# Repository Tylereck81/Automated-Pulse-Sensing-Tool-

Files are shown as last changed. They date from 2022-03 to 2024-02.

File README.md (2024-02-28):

# Automated Pulse Sensing Tool
APST_mainpic 

2021-2022 NDHU Undergraduate Project  
Group Members: Tyler Edwardo Eck  
Advisor: 顏士淨 (Shi-Jim Yen)  

## Introduction 
Automated Pulse Sensing Tool is a tool that allows users to measure their pulse with ease. With the simple push of a button, this tool will detect the pulse location on a person's wrist, move the sensor to that location, and record the TCM (Tradional Chinese Medicine) pulse readings. Finally, the results will be automatically uploaded to the cloud for remote doctors to observe.    

This project, including both the hardware and software, was exclusively developed and submitted as my final entry for the 2021 NDHU Undergraduate Project.      

Within the repository, you will find both the documentations for the project, including the presentations, poster, and research report, and the two main programs used together to control the tool. 

## Hardware 
The Automated Pulse Sensing Tool incorporates multiple hardware components that work together to give the tool its utility. The following is what was used:     
     
### Creality CR10s 3D printer   
The recycled 3D printer was used as the main base for my project. It provides a main hand-rest area for patients with all the necessary motors and stop switches connected in an X,Y, and Z plane.     
    

### HK-2019 Cylindrical Pusle Sensor 
This 200Hz pulse sensor measures both pulse and pressure for TCM pulse points.    
 

### StereoLabs ZED dual camera 
The camera was specifically chosen for its high frame rate and long-range 3D sensing.    
 

### 3D-printed Component 
This 3D printed component was designed to mount the camera and sensors together for the motors to move.    
 

### Final Tool 
The completed hardware with all the subcomponents mentioned above is shown below.  
 
    
## Software 
The Automated Pulse Sensing Tool needs software to move step motors through Arduino and a Python program to communicate with Arduino and process motor movement. The Python program also acts as the main GUI that patients and doctors will interact with. Therefore, in the Hardware/Arduino folder, the "Motor_Movement.ino" is used to move the motors and in the Software GUI folder, "APST_GUI.py" is the main python program.     
     
The APST_GUI.py was designed and implemented using Tkinter, a package in the standard Python interface GUI toolkit. As shown in diagram below, the GUI consists of 4 main parts: 

label

1. Camera - shows users a live feed of the camera and its detection of the pulse point.   
     
2. Options - controls motors manually with arrows and step selection, controls initiation of scan, and displays connection information regarding the pulse sensors, motors, and camera.  
   
3. Graph - displays the graph of the pulse that was taken.    
   
4. Information - allows users to enter additional information about the graph including name, date, and description (optional). This section also includes the Upload button that is necessary to send data via Firebase to the cloud.    

## Setup
The Automated Pulse Sensing Tool requires both the necessary software configurations and the physical tool available in order to sucessfully record and upload data. However, because the physical tool is property of the NDHU AI Lab, I can only include the software configurations to run the main python GUI program.    

In order to run the programs locally, follow the necessary steps below:    

1.  Download and install [Anaconda](https://docs.anaconda.com/anaconda/install/index.html) - Python 3.5 or 3.6
     
2.   Create an environment and download the necessary packages below using "conda install".   
     * Numpy 
     * Matplotlib
     * Tk - Tkinter 
     * Pillow - Image, ImageTk
     * OpenCv
     * Serial 
     * Mediapipe 
     * Pyrebase
   
3. Download and install [Arduino IDE](https://www.arduino.cc/en/software)
4. Download USB Driver for the HK2019 Pulse and Pressure Sensor - instructions and website found in "USB-- READ ME--" file in project. 
5. Upload "Motor_Movement" file to the Arduino Board using Arduino IDE. 
6. Run the main "APST_GUI" python file.

If all steps were properly executed, the main GUI screen will appear as shown below.

<p align="center">
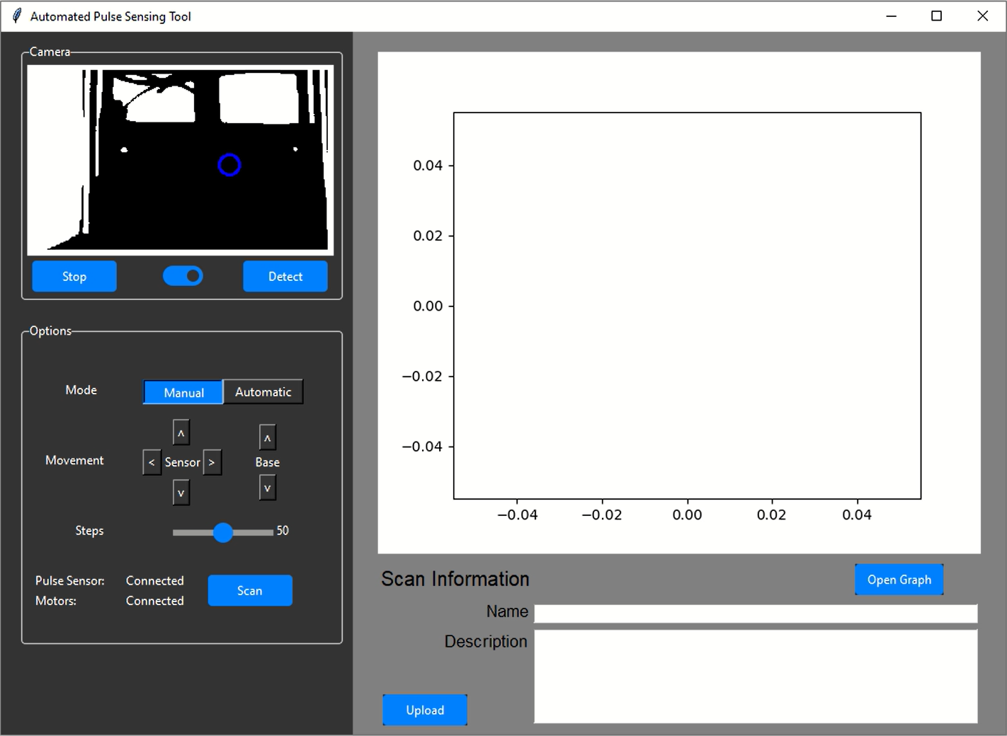
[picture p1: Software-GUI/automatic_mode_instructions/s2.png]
  
</p>

## Instructions
In order to run the program successfully, ensure the pulse sensor, arduino, and camera are all connected via USB and the computer recongizes them.
 
The two modes that are available are Manual and Automatic. Manual is selected by default.    

 * ### Manual 
Manual mode is intended for doctors to use as they are given the choice to manually move the motors and start scan when desired. The following steps are the sequence that doctors can follow:
     
1. The motor movement is initiated through the Options menu shown below. The sensor can be moved on the X and Z axis by through the Sensor movement arrows. The base, where the patients hand would lay, can also be moved on the Y axis through the Base movement arrows. Lastly, the doctors can manually control the steps that the motors can take for a given click of the arrow. By adjusting the Steps slider, each movement can be shortened or lengthened.      
          
op      
     
2. After a desired location is reached, the doctor can activate the detection algorithm, through the "Detect" button in the Camera section, to determine if the location of the pulse point is in the blue circle; this blue circle displays the exact point where the sensor will read. The "Stop" button is used to freeze the frame so that the doctor may have a chance to click on the point that the sensor should move to. Clicking the point activates the motor movement to have the sensor move directly beneath the selected pulse point.       
     
        

3. When ready to scan, the "Scan" button in the Options menu should be pressed. A seperate screen will pop up to indicate the scan is taking place. When finished, the "Stop" button should then be pressed to stop the scan. To see a more detailed version of the recorded graph, the "Open Graph" button in the graph section can be pressed. To "cut" or record a subsection of the graph, the mouse's left click is used to select start point and right click to select end point.
      
g5
       
g2
     
5.  Lastly, information about the patient can be entered in text area and uploaded by pressing the Upload button.    
     
u5

* ### Automatic
Automatic mode is intended for patients to use and includes user-friendly instructions that patients should read carefully. 

1. When the Automatic button is pressed in the Options section, a seperate instruction screen will appear for users to read. These instructions include different warnings and proper hand form for an accurate scan.    

     
         
      

2. After the instructions have been read, the "Finish" button will be enabled to press which starts the automation process. The tool will automatically detect the pulse point, select the pulse point, move motors to that point, and scan for 30 seconds. When finished, the patient will be prompted to enter information and then press the "Upload" button as shown in the Manual section.

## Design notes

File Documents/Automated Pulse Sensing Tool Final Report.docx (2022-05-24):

國立東華大學資訊工程系

Automated Pulse Sensing Tool

National Dong Hwa University

110學年度大學部畢業專題研究報告

110 CSIE Undergraduate Project Report

指導教授Advisor: 顏士淨 (Shi-Jim Yen)

專題參與人員Team Member: Tyler Edwardo Eck

中 華 民 國　　111 　年　　05　　月 　20 　 日

國立東華大學資訊工程學系

專題報告原創性聲明

National Dong Hwa University

Department of Computer Science and Information Engineering

Statement of Originality

本人鄭重聲明：

所呈交的專題報告是在指導老師指導下進行的研究工作及取得的研究成果。除文中已經註明引用的內容外，本報告不包含任何其他個人或集體已經發表或撰寫過的研究成果。對本文的研究做出重要貢獻的個人與集體，均已在文中以明確方式標明。若有違上述聲明，願依校規處分及承擔法律責任。

I hereby affirm that the submitted project report is the result of research under the supervision of my advisor. Except where due references are made, the report contains no material previously published or written by another person or group. All significant facilitators to the project have been mentioned explicitly. Should any part of the statement be breached, I am subject to the punishment enforced by the University and any legal responsibility incurred.

學號Student No. | 學生姓名Name | 親筆簽名Signature

. 410821337 Tyler Edwardo Eck .

日 期 Date: 5/20/2022

ACKNOWLEDGEMENTS

In the process of conducting this project, I have received an abundance of support.

Firstly, I would like to thank my Advisor, Professor 顏士淨 (Shi-Jim Yen), for the assistance and resources needed to conduct such a complex project. The guidance that he gave me helped to overcome many problems that I found myself stuck with. Moreover, his expertise and knowledge in this field gave me insight into the paths that I had taken to complete this project.

I would also like to thank邱顯棟 (Jelly) and Serkan Kavak, two employees of the AI Lab, whose advice and one-on-one help pushed me to overcome the many programming obstacles that stood in my way.

With the help of the ⼨關尺辨 識 team and permission from my advisor, I was able to implement their pulse point detection algorithm into my tool. Without this, my project would not have been as engaging and practical.

Lastly, I would like to thank my parents, family, and friends whose value of support was immeasurable. Without this, I wouldn’t have pushed myself hard enough to make this project the best that it could be. They helped keep me grounded and were there to lend a helping hand if needed.

ABSTRACT

Due to the rise in popularity of technology, especially of the internet, people have sought to use creative and functional methods of implementing it in their daily life. Automation, for instance, can have a huge impact in the amount of time saved doing remedial tasks. As seen in the manufacturing sector, both throughput and speed are pushed to the limit with industrial robots in the place of working human beings. This exponential improvement that automation brings should be applied to something more important such as the medical field.

Combining automation with medical tools creates a crossroad for the tool proposed in this project. With an automated pulse sensor that can remotely record a person’s pulse faster, medical checkups for the elderly living in remote areas becomes easier and more efficient. By using a cloud-based platform, this tool can also give doctors the ability to remotely observe multiple people’s pulse recordings at any given time. Limitations on location and time would be eradicated as a result of the implementation of this tool.

Keywords: automation, medical, pulse, cloud-based

CONTENTS

Statement of Originality …………………………………………………1

Acknowledgments ……………………………………………………….2

Abstract …………………………………………………………………...3

Introduction ……………………………………………………………….5

Motivation and Research Problem ……………………….…………....7

Research Method ………………………………………………………..8

Program Execution ……………………………………………………..15

Research Results (Discussion) ………………………………………..25

Conclusion ……………………………………………………………….28

References ……………………………………………………………....29

INTRODUCTION

In this evolving technological era, it is common to find ourselves dependent on automation technology whether it may be for a simple smart home device or something more complex such as a self-driving car (autonomous vehicle). Regardless, it is important to note that this fundamental use of automation can have a drastic impact on our seemingly difficult life. As popularity and demand grow, I believe that the next logical step is to implement automation in more important roles such as for medical purposes. By doing this, more time will be saved which may potentially save more lives.

Due to its popularity here in Eastern Taiwan, the specific medical procedure that I want to automate is pulse diagnosis in Traditional Chinese Medicine (TCM). As opposed to pulse diagnosis in western medicine that retrieves little information from a single point, TCM pulse diagnosis focuses on three locations, cun, guan and chi, on a person’s wrist to get the condition of the heart, liver, and kidney respectively. Although it is argued that TCM pulse diagnosis results are biased and only dependent on the practitioner’s experience and intuition, there have been many studies that aim to quantify the methods and assessments that can be drawn from the diagnosis. Moreover, most of the Taiwanese population, especially the elderly, rely on TCM assessments and consultations when they’re sick.

Therefore, with the advantages that automation brings and the popularity of Traditional Chinese Medicine in Taiwan, I propose a fully automated pulse sensing tool that will allow for users to measure their pulse with ease.

With the simple push of a button, this tool will detect the pulse location on a person’s wrist, move the pulse sensor to that location, and then finally make a digital recording of the pulse reading that will automatically be uploaded to the cloud.

As a result, the pulse reading can be analyzed by a doctor anywhere in the world making it more convenient for patients to see the doctors and for doctors to analyze and assess pulse diagnosis.

MOTIVATION AND RESARCH PROBLEM

Technology has solved many of our proximity problems whether it may be remote schooling due to COVID-19 or online conferences for company chains in different locations. The value of being able to connect with each other regardless of our location is quite essential in this modern age. Although we take it for granted, this idea of connection must be pushed to its limit. Therefore, the motivation of this project is to extend this connection to people who are physically unable to go for frequent doctor visits as a result of living in remote areas.

Small villages, especially in the east of Taiwan, lack the efficient number of doctors and special experts that are needed due to high numbers of elderly population living in those areas. Because of this, a lot of people need to travel far distances just to get a routine check-up. This poses a problem when they are physically unable to go due to health conditions, lack of transport, or the dynamic COVID-19 restrictions. The proposed tool allows for convenience as the goal is to make it accessible for people to send their information remotely to the doctor for examination.

RESEARCH METHOD

The project’s goal was to make an automated system that remotely transmits data. It needed both the necessary hardware to move motors and measure the pulse and the necessary software for detection of the wrist location, GUI for users, and the transmission of data. Therefore, I have split the project into two main parts as shown below: hardware and software

I. Hardware

The three main hardware components necessary to complete the project were the step motors to move the sensor, the camera as digital input for detection, and the pulse sensor to measure the pulse. Fortunately, I was provided with a Creality CR10s 3D printer that had all the necessary motors with its stop switches connected in an X,Y,Z plane shown below in Figure 1.

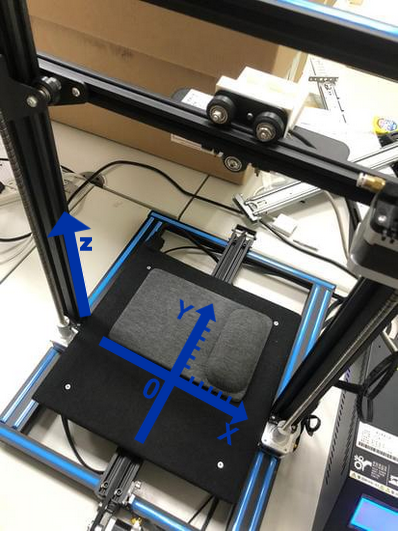
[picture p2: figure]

Figure 1: 3D printer with dimensions

The repurposing of this 3D printer required reprogramming the stepper motors that were connected to the motherboard. The motherboard, which is housed separately with the battery, is an Arduino2560 microcontroller and can therefore be controlled using the Arduino IDE. After the reprogramming was done, the motors could move in accordance with the X, Y, and Z Cartesian plane based on coordinates that was supplied to it through the serial.

The pulse sensor and camera were both provided by the lab as well. The pulse sensor is a HK-2019 Cylindrical Pulse Sensor. This 200Hz pulse sensor, as shown in Figure 2 (left), measures both pulse and pressure. The camera is a StereoLabs ZED dual camera as shown in Figure 2 (right). Because the website specifically advertises it for autonomous robotics due to its high frame rate and long-range 3D sensing, it was selected for the project.

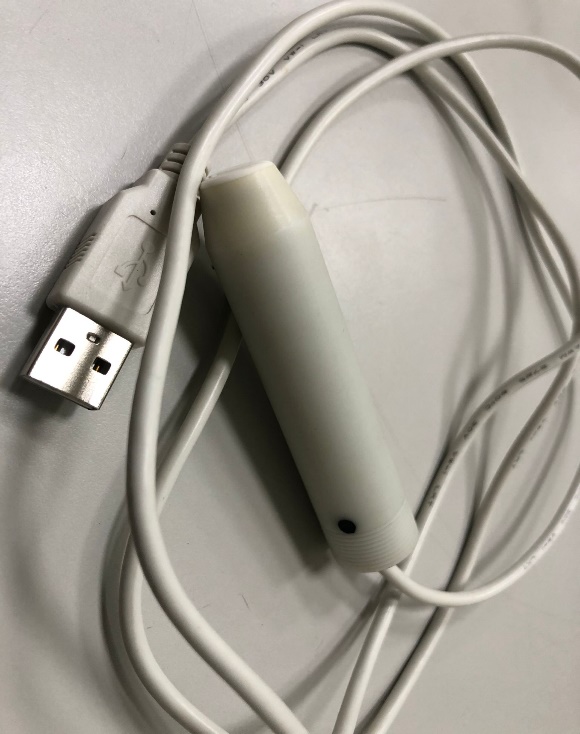
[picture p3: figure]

Figure 2: Pulse Sensor and ZED Dual Camera

Lastly, to mount both the camera and the sensor together for the motors to move, I had to learn how to design a 3D model and how to print using a 3D printer. Fortunately, the lab had a functioning 3D printer to my disposal, so I designed and printed a 3D-printed part shown below in Figure 3. (On the left shows the design of the part in the software and the right shows the printed piece).

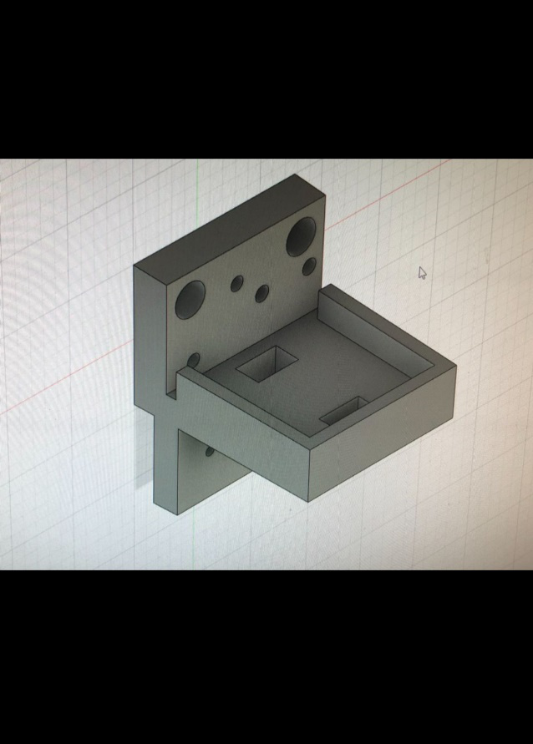
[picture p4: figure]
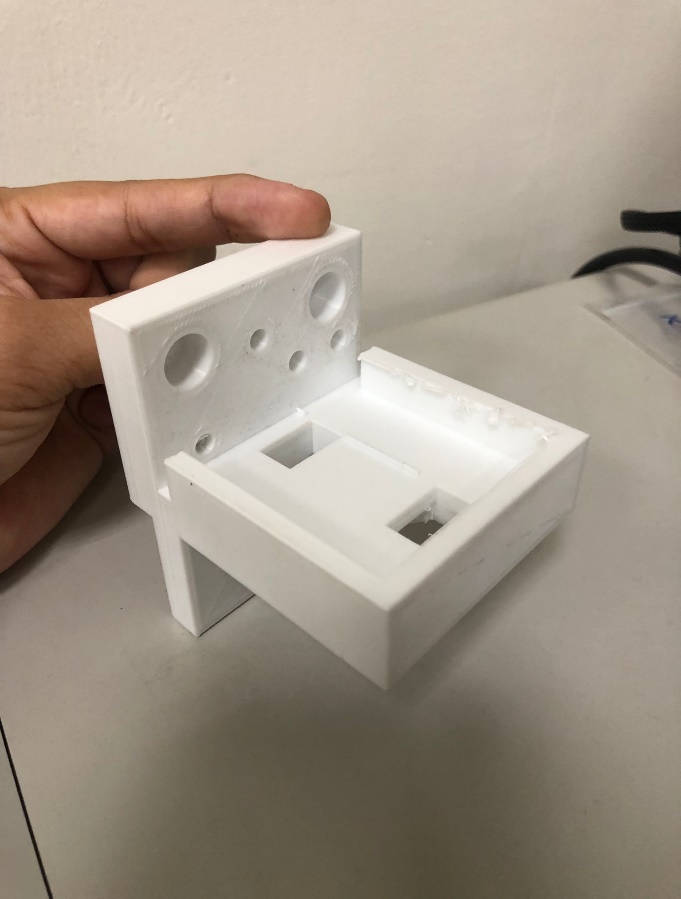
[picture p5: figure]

Figure 3: 3D-printed part

After all the necessary hardware configurations were done, the right USB drivers were installed, and USB extensions were added to each hardware component, the final hardware product was completed.

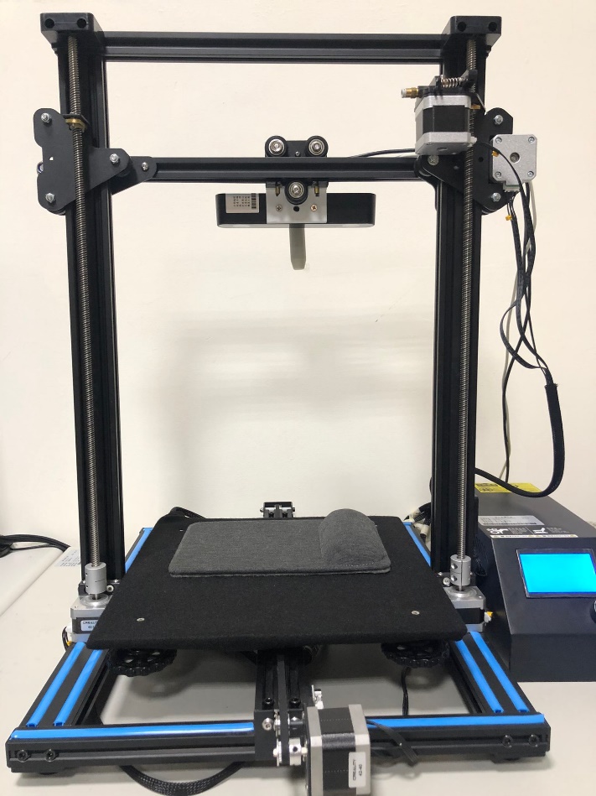
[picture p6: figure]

Figure 4: Completed Hardware

II. Software

There were two main portions of the project that consisted of software: The reprogramming of the Arduino and the GUI for the doctors/patients to use. These two programs will communicate with each other via the serial to have the motors move based on the specifications made in the GUI, thus successfully connecting the hardware and the software together.

The Arduino language, which is a language that uses C++, is a simple language used for the wiring and programming of Arduino microcontroller boards. As stated in the Hardware section, the motherboard used in the Creality 3D printer is an Arduino Mega 2560 running Marlin 2.0, the firmware used for all Creality printers. However, with simple programming done in the Arduino IDE, I successfully wrote a function that would constantly listen for coordinates through the serial. With these coordinates, I moved the X,Y, and Z coordinate motors with the help of an official Arduino library called SpeedyStepper. Shown below is a snippet of the Arduino code that constantly loops to listen for coordinates.

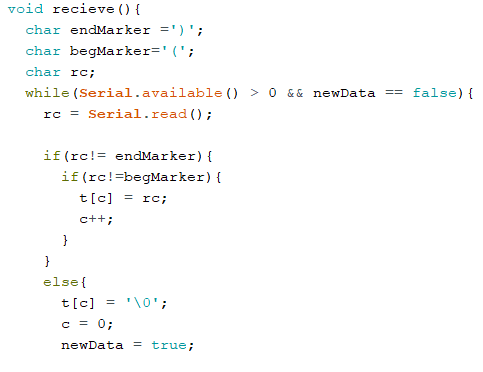
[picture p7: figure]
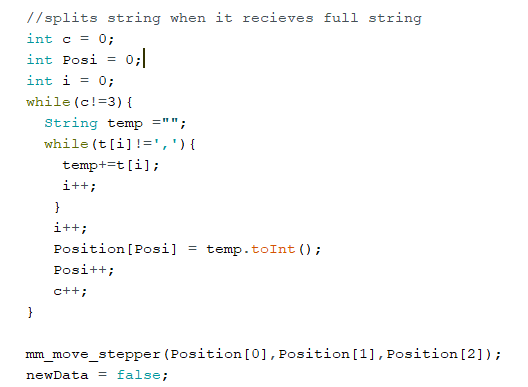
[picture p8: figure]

Figure 5: Arduino Code

Based on previous knowledge of GUI designing and implementation, I decided to use Tkinter, a package in the standard Python interface GUI toolkit, to construct a user-friendly interface for the doctors and patients to use. As shown below in Figure 6, the GUI consists of 4 parts:

1.) Camera – the section on the top left to show users a live feed of the camera and its detection of the pulse point
2.) Options – the section on the bottom left to switch between the two main modes: Manual and Automatic, control the motors manually with arrows and step selection, and start the scan when needed. The section also gives connection information regarding the pulse sensor, motors, and camera.
3.) Graph – the section to display, examine, and manipulate the graph taken.
4.) Information – the section on the bottom right to give additional information of the graph including the name, date, and a description (if needed). After all necessary information is inputted, an upload button allows for the user to send the data via Firebase to the cloud for evaluation.

Figure 6: Automated Pulse Sensing Tool GUI

Lastly, the detection algorithm used to detect the pulse point was developed by the ⼨關尺辨 識 group and was implemented into this project. The algorithm calculates the point by using a Python package called Mediapipe. As shown below, Mediapipe can detect a hand and identify 21 uniquely marked points on the hand known as landmarks. It is with 11 of these 21 landmarks that the algorithm calculates and marks the points in the Camera section.

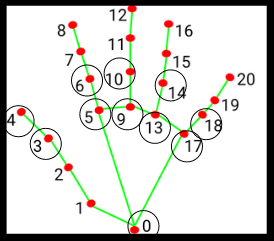
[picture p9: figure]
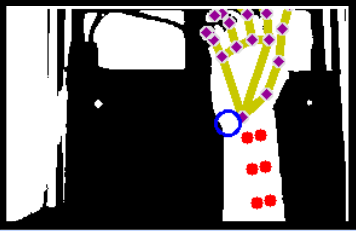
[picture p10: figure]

Figure 7: Automated Pulse Sensing Tool GUI

PROGRAM EXECUTION

The main flow of the program starts with the detection and recognition of all connected devices, including the motors from the Arduino, the pulse sensor, and the camera that are all connected via USB. After everything is confirmed to be connected, the user must select one of the two modes to run: Manual or Automatic

The default mode, manual mode, allows for a more interactive and hands-on experience which would most likely be done by a doctor. Movement of the motors can simply be done by selecting the number of millimeters each press should take and then pressing the Up, Down, Left, and Right buttons located in the Options section as shown in Figure 8.

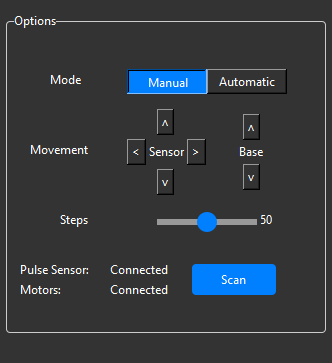
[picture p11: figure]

Figure 8: Manual Mode: Selection of Cm per Step

To aid the doctor in reaching the proper x and y coordinate of the pulse point, the detect button should be pressed to activate the detection algorithm. The live camera feed will display the calculated and marked pulse point on the screen. Due to its fast-dynamic calculations, the algorithm’s marking may change abruptly. To combat this, the Stop button should be pressed to stop the frame of the camera. From this point, the doctor can press where the pulse sensor, which is marked on the screen as a blue circle, should go and the motors will move to that location. Shown below in Figure 9 is the flow of this operation.

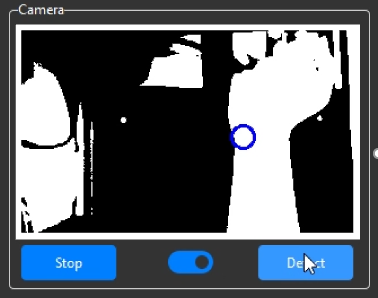
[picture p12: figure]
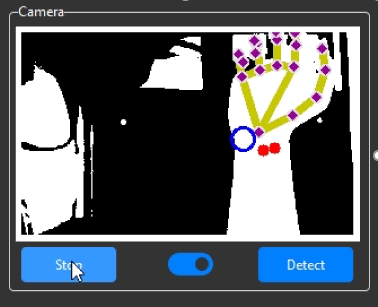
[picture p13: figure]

Figure 9: Manual Mode: Detection of Pulse Location

After the x and y coordinates have been reached, the doctor can then manually move the Z-axis sensor motor to the necessary height. When the desired location is reached, the scan button can then be pressed to graph the pulse and pressure taken from the pulse sensor and the stop button can be pressed to finish scanning and display the graph in the Graph section. If the doctor chooses to edit the graph, a button called “Open Graph”, located below the graph, can be pressed. The Open Graph window, shown in Figure 10.2, will display the graph and allow the doctor to select a snippet by left clicking for the start position and right clicking for the end position. When finished, the selected snippet, indicated by a red hue, will display as the graph on the main application.

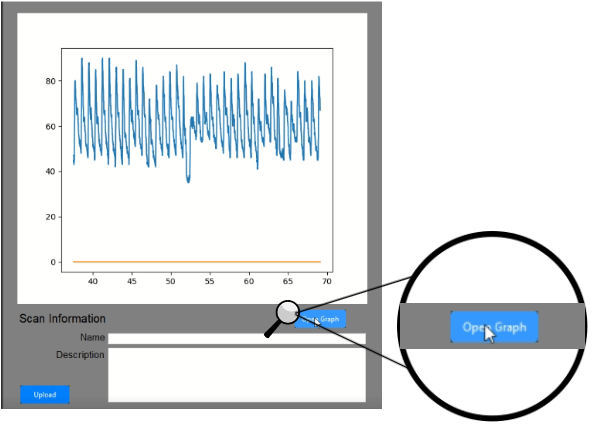
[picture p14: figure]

Figure 10.1: Manual Mode: Edit the Graph

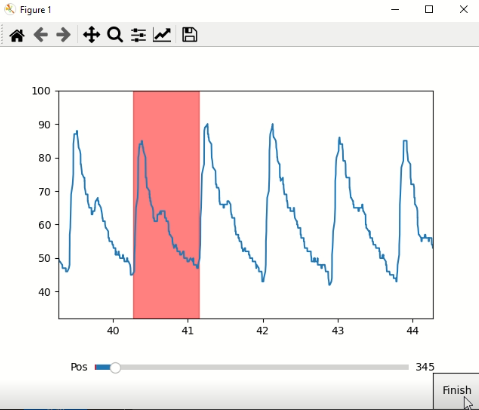
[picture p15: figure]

Figure 10.2: Manual Mode: Edit the Graph

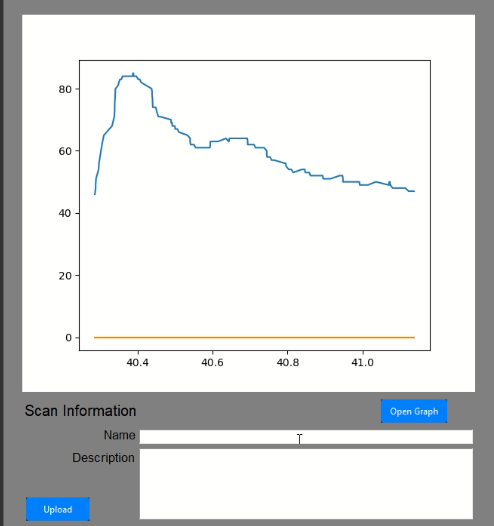
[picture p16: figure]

Figure 10.3: Manual Mode: Edit the Graph

Lastly, the name and description areas are for the doctors to fill in necessary information regarding the pulse scan. The Upload Button should then be pressed to upload files to Firebase Storage. As shown below in Figure 11, the two files that are uploaded, the picture of the reading and the information text file, are both inserted into folders named after the patient.

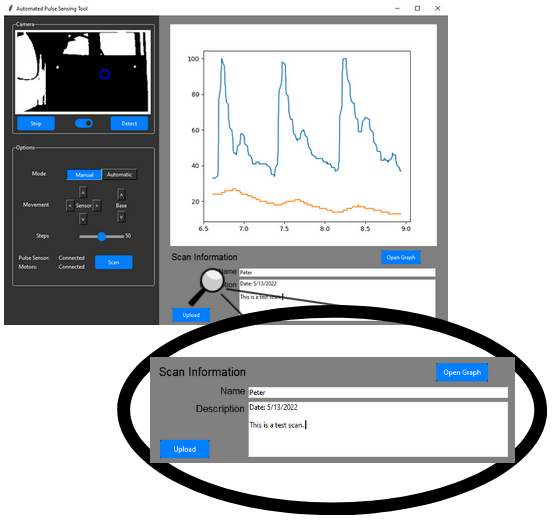
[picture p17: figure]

Figure 11.1: Manual Mode: Upload Graph

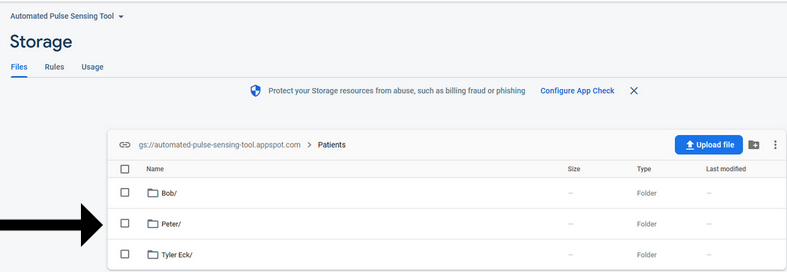
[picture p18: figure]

Figure 11.2: Manual Mode: Upload Graph

Figure 11.3: Manual Mode: Upload Graph

Automatic mode does the detection of the pulse point via the camera, the movement of the motors based on that pulse point, and the scanning of the pulse automatically. As a result, the patient would just need to enter their name and other information and then upload the scan. Because this mode is intended for the general user (patients), when the Automatic button is pressed, a series of instructions are displayed. The user will need to read these instructions before the automation occurs. Shown below are the instruction pages.

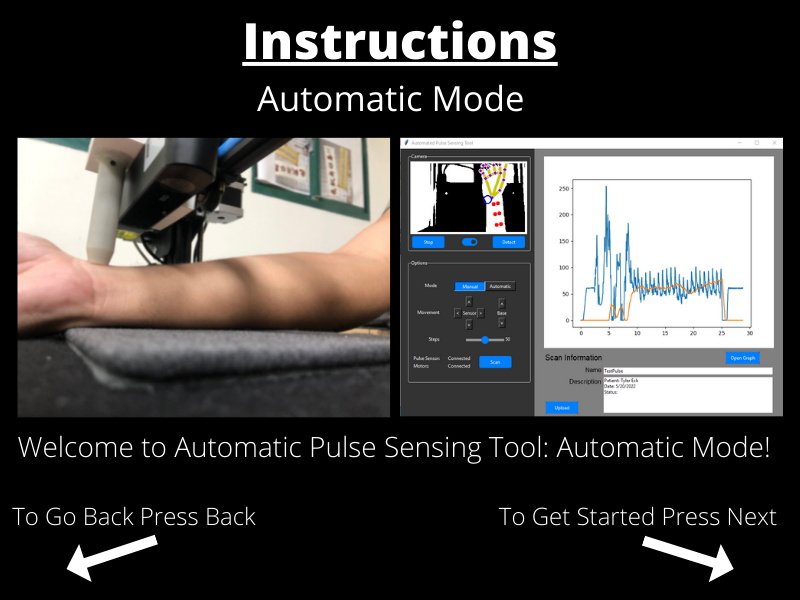
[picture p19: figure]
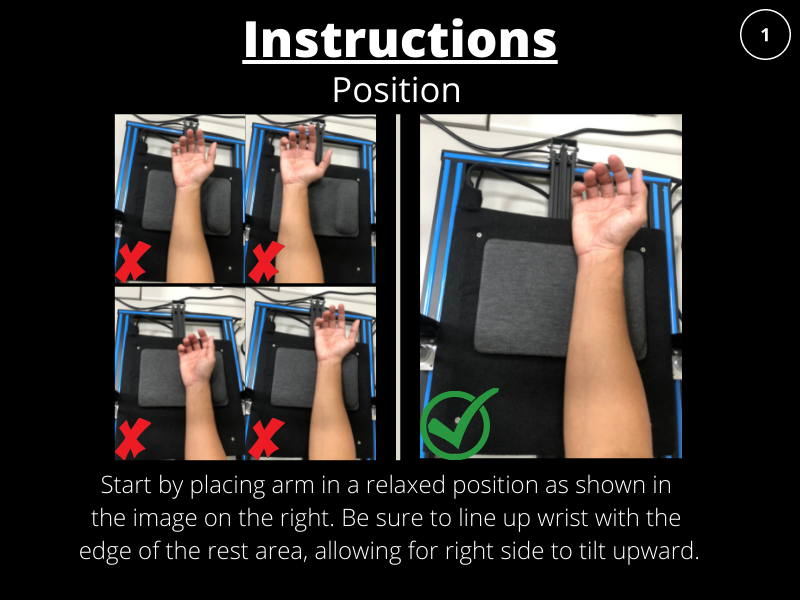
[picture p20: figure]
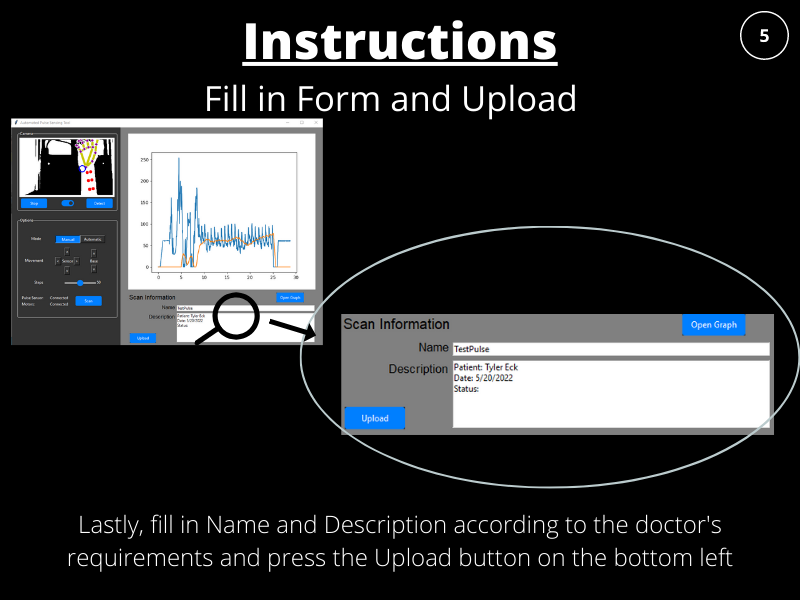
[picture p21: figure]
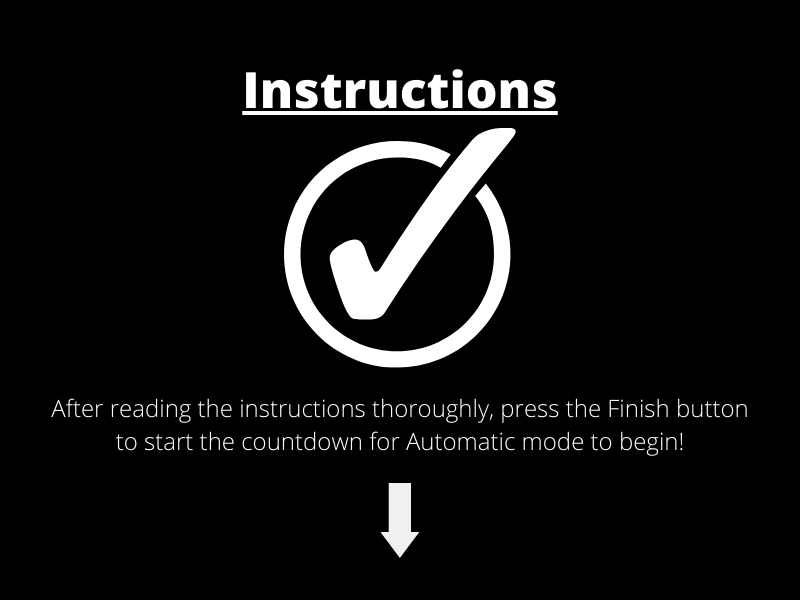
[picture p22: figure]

RESEARCH RESULTS (DISCUSSION)

The tool’s functionality and ease of use allows for both the doctors and the patients to understand how to use the program and automate the task of getting the pulse successfully. However, the actual tool that was built is a “proof of concept” and needs further research to be tested by a real TCM doctor. Moreover, even if all requirements are met for testing, official safety guidelines will need to be followed because it is a medical tool that will be used on patients.

The only results that can be discussed are about the pulse readings that are measured after automation occurs in the Automatic Mode of this tool. The goal to automatically detect the right pulse point and move motors to that point can be verified by the digital pulse reading that is recorded. For the sake of simplicity, the only detection point that was implemented in this tool was the “cun” point on the right hand as shown in Figure 12. The pressure for all these tests were also kept low.

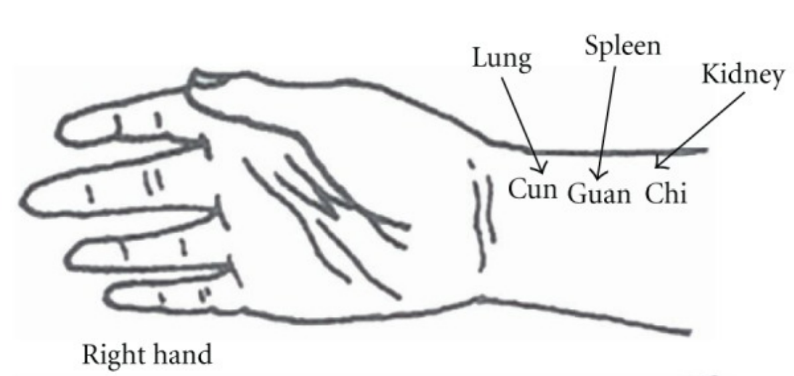
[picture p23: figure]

Figure 12: Cun Point on Right Hand

If the motors move the pulse sensor to a Z height barely touching the skin, a flat line for the pulse and the pressure will be recorded as shown in Figure 13.

Figure 13: Wrong Z Height: Constant Line

If the motors move the pulse sensor to a wrong X,Y coordinate that is not the proper pulse point, noisy data will be gotten as shown in Figure 14.

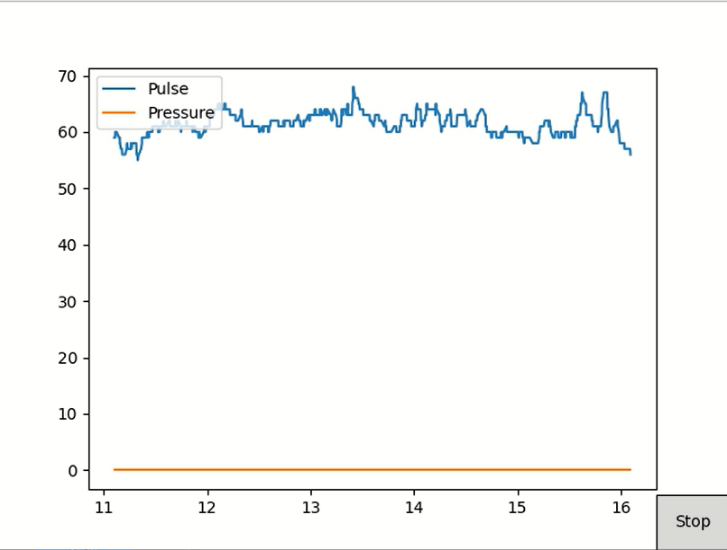
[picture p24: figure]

Figure 14: Wrong X,Y Point: Noisy Data

Lastly, if the motors move the pulse sensor to right X,Y, and Z coordinate, the indication that a proper pulse reading was gotten is shown in Figure 15.

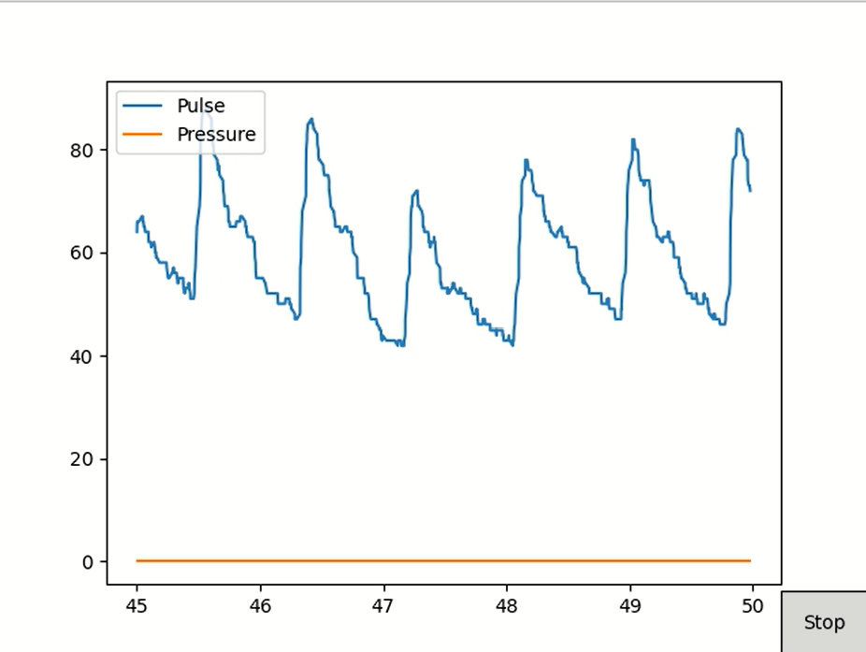
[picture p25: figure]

Figure 15: Correct X,Y, and Z: Proper Pulse Reading

The different readings from my tests show a clear distinction between the wrong pulse point and the right pulse point. Moreover, Figure 16 shows the clear similarities between a reading done by the Automated Pulse Sensing Tool and the pulse pattern of a healthy person therefore validating the tool’s pulse reading.

Figure 16: Pulse Pattern Comparison

CONCLUSION

The aim of this project was to design and implement an automated pulse sensing tool that automatically detects the pulse point, moves the pulse sensor to that pulse point, and reads and uploads the results. Due to the similarities between official pulse readings and the tested readings, it can be concluded that both the hardware and software of this project proved to be functional. Moreover, the simplicity of the GUI, with the Automatic Mode instructions, allowed for users of the Automated Pulse Sensing Tool to measure their pulse with ease.

Although the tool could not be properly implemented, the accurate results and the successful integration of Firebase proved to show that a tool like this could be useful to patients who live in remote areas.

Future goals for this project, if it were to be continued, are to add other points “guan” and “chi”, increase accurateness of detection, and even add a language section to switch between Chinese and English. However, for the sake of this undergraduate project, the tool was sufficient enough to demo and yield proper results.

REFERENCES

- https://www.intechopen.com/chapters/40015
- https://www.researchgate.net/figure/A-C-pulse-patterns-of-young-healthy-persons-A-taut-B-slippery-C-moderate-Plot_fig3_236266843
- http://www.hfhuake.com/Article.asp?pid=145&id=361
- http://www.empirical-health.com/services/pulse-diagnosis/
- https://www.ncbi.nlm.nih.gov/pmc/articles/PMC7472259/

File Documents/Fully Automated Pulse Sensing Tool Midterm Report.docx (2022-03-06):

Fully Automated Pulse Sensing Tool

Undergraduate Project: Midterm Report

Name: Tyler Eck

Student ID: 410821337

Advisor: Shi-Jim Yen 顏士淨

# Introduction

In this evolving technological era, automation is slowly finding its way into our daily lives. With its convenience and consistency, automation allows for users to hand over control to machines to do repetitive and trivial tasks. The most popular example of this is smart home devices that allow homeowners to automate things in their house such as lights for energy conservation and the door lock for security. As popularity and demand grow, I believe the next logical step is to implement automation in a more important role such as for medical purposes. Therefore, in this project, I propose a fully automated pulse sensing tool that will allow for a user to measure their pulse with ease. With a simple push of a button, a special camera will detect where the user’s pulse should be measured and move the pulse sensor automatically to that location on the wrist. As a result, the pulse will be measured accurately and the information can be sent remotely to any location, which would ideally be a doctor for analysis.

# Research Motivation

The motivation for this project originated as a result of people being unable to go for frequent doctor visits due to living in remote areas. Small villages, especially in the east of Taiwan, lack doctors and special experts that are needed due to high numbers of elderly population living in those areas. Because of this, a lot of people need to travel far distances just to get a routine check-up. The proposed tool allows for convenience as the goal is to make it accessible for people to send their information remotely to the doctor for examination. Another advantage of this tool will allow doctors to track progress of the electrocardiogram (ECG) pulse reports to detect problems in the patient. The ease of access for both the doctors and the patients despite proximity problems allows for this tool to potentially have a high demand and make a significant impact on how people see the doctor.

# Project Plan

The project’s goal is to make an automated system that remotely transmits data. It will need both the necessary equipment (hardware) to move motors and measure the pulse and the necessary software for detection of the wrist location and the transmission of data.

I. Hardware

The three main hardware components that I will need are the stepper motors to move the sensor, the camera as a digital input for detection, and the pulse sensor to measure the pulse. Fortunately, I am provided with a Creality CR10s 3D printer that has all the necessary motors with its stop switches connected in an X, Y, Z plane shown below in Figure 1.


Figure 1: 3D printer with dimensions

The repurposing of this 3D printer requires a reprogramming of the stepper motors that are connected to the motherboard. The motherboard, which is housed separately with the battery and the screen, is an Arduino2560 microcontroller and can therefore be controlled using the Arduino IDE (the motherboard with the stepper motor connections is labelled in Figure 2). After the reprogramming is done, the motors should move in accordance with the X, Y, and Z Cartesian plane.


Figure 2: Creality V2.1 Motherboard

The pulse sensor and camera are both standard devices with no specific type for this project. However, the camera and the sensor need to be mounted together for accurate detection and movement. Therefore, a 3D printed plastic connection will be designed and printed to accommodate both the sensor and the camera together.

Lastly, the simple abstract flow of the program will run as shown below in Figure 3. The camera feed/picture will be the input to the detection algorithm. The detection algorithm will detect the pulse point and output the necessary x, y, and z values to use as inputs to our motor function. Lastly, the motor function will accept these inputs and move to the desired destination for the pulse information to be recorded and uploaded.


Figure 3: Fully Automated Pulse Sensing Tool Abstract Model

II. Detection Method

There are multiple detection methods that can be applied to detect the pulse point in a person’s wrist. I don’t believe I will train the model, but I will use a preexisting trained model for detection. Papers such as “Accurate targeting in robot-assisted TCM pulse diagnosis using adaptive sensor fusion” (Luo, Ouyang, et al.) and “Pulse Localization Networks with Infrared Camera” (Yang, Meng, et al.) will be used as a framework of comparison as to how to implement it. The latter method uses an infrared camera which allows for even a more accurate result. However, at this moment I have not yet decided on what method to use. A final decision will be based on both my advisor’s recommendation and the apparatus that is available to me. Nevertheless, it will be implemented to detect the pulse point and there will need to be a function in place to detect at what x, y, and z location the pulse sensor must be moved to.

III. Cloud

Lastly, after the pulse data is collected, it will need to be uploaded to cloud-based database. For the purpose of the project, I can either use Supabase or Firebase to upload the EKG information. Regardless of which I use, using a cloud-based database allows for ease of access to any doctor anywhere in Taiwan.


# Progress

Most of the time was spent on research and design this semester. As shown above, the plan is still in its primary stages and needs much work. However, the one thing that has been completed is the function to move the motors freely. By researching the different motherboards and searching through the source code of the Marlin firmware, the specific pins that the motors were connected to were identified. With this, I successfully created a function to move the stepper motors freely. This integral part of the project is a small contribution; however, most of the research and planning are done and all that is left to do is to implement. Although I am the sole group member, I will be putting in time throughout this winter break and throughout next semester to implement this fully automated pulse sensing tool.

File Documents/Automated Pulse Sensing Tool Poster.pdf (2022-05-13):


## IMPLEMENTATION

Hardware | Software


## (X,Y,Z)

### Mediapipe Hand Landmarks

# Automated Pulse Sensing Tool

## INTRODUCTION

Automation technology is slowly progressing into our daily lives whether it may be for a simple smart home device or for a complex fully autonomous vehicle. With its rise in popularity, the next logical step of progression should be used for medical tools as its implementation could potentially save lives.

Traditional Chinese Medicine (TCM) pulse diagnosis is the specific procedure that will be automated in this project. TCM pulse diagnosis focuses on three location: cun, guan, and chi, on a person's wrist. With the pulse readings of these three points, each with different levels of pressure, a TCM doctor can make assessments of the body parts and diagnosis the patient if needed.

## RESULTS

## OBJECTIVE

The main objective is to design and implement a fully automated pulse sensing tool that will allow for users to measure their pulse with ease.

With the push of a button, the tool will detect the pulse location, move the sensor to that location, digitally record the pulse reading and upload it to the cloud for the doctor's observation.


Automated Pulse Sensing Tool

## CONCLUSION

Arduino Mega
2560

X,Y,Z Step Motors

Stereolabs Zed
Camera

HK 2019 Pulse
Sensor

Python Tkinter
GUI

Arduino Motor
Control

Pulse Detection

Firebase
Configuration

NDHU Undergraduate Project Author: Tyler Eck
Advisor: 顏士淨 (Shi-Jim Yen)

HARDWARE
The main base was formed by repurposing a Creality 3D printer with the X,Y, and Z motors already incorporated. The motherboard is an Arduino Mega 2560 and was reprogrammed to move motors freely. The Zed camera and the HK Pulse Sensor was mounted to the moving motors with a specially desgined 3D printed part shown below.

SOFTWARE
The main GUI program was written in Python using the popular GUI package Tkinter. In order to communicate with the Arduino, a Motor Movement function was written and uploaded to the Arduino in order to always listen for commands given by the main program. If any movement is required, coordinates (X,Y,Z) will be sent to the Arduino through serial.
Up++ | Motor Move (F)

## F(X,Y,Z)

Main GUI | Arduino | Step Motors

The pulse detection point was calculated and identified by using a Python package called Mediapipe. As shown below, implementing Mediapipe can allow for hand detection with 21 marked points known as hand landmarks. With 11 of these landmarks, the pulse point was calculated using an algorithm developed by the 寸關尺辨 識 team who are also members of the AI Lab.

### Pulse Detection Result

Automated Pulse Sensing Tool GUI

On the left shows the hardware implementation of the Automated Pulse Sensing Tool with the connected camera, motors and sensor to the main base. On the right shows the GUI implementation of the Automated Pulse Sensing Tool with the live camera feed, configuration menu, and graph display.


Due to the similarities of shape to an official arterial pressure pulse form shown on the right, the automated tool proved to be effective in both finding and moving to the correct pulse point and recording and graphing the pulse reading properly

The implementation and testing of this tool proved to successful. However, in order to get proper data to improve the detection algorithm and motor movement translation, this tool will need to be implemented in a hospital and tested by a TCM doctor.

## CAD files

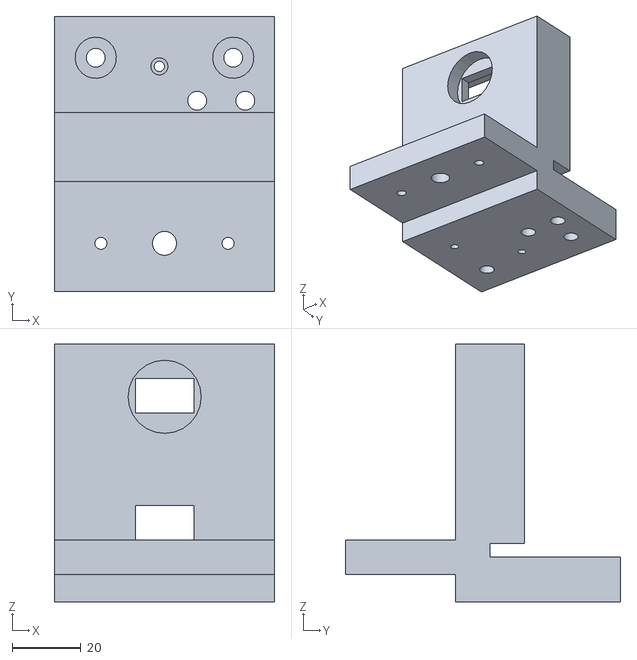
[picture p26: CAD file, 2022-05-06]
Hardware/3D Pulse_Camera Design/Pulse Hold Piece v2.obj
64.0 x 80.0 x 75.0

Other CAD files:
Hardware/3D Pulse_Camera Design/Sensor_Camera_v2 .stl
Hardware/3D Pulse_Camera Design/Pulse Hold Piece v1.obj
Hardware/3D Pulse_Camera Design/Pulse Hold Piece v1.f3d

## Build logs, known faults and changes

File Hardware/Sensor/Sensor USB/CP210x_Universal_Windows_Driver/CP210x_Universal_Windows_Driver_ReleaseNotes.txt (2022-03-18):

RELEASE NOTES
=============
Silicon Labs Virtual COM Port (VCP) Universal Driver for Windows 10 and later

Package version: 11.0.0
Release date:    2021-11-05

This package contains a Virtual COM Port Universal driver for Microsoft
Windows 10 and later versions of Windows for use with Silicon Labs VCP USB Serial Bridges.  These devices
include the CP2102N, CP2102, CP2103, CP2104, CP2105, CP2108, CP2109.

OS VERSIONS
-----------
This package provides the CP210x VCP driver for the following versions
of Windows:

- Windows 10    (x64, x86)
- Windows 11    (x64)

CHOOSING VCP DRIVER VERSION
---------------------------
VCP drivers of version 10.0.0 and later are released for Windows 10 and later
versions of Windows as Universal Drivers.
This means they do not work on older version of Windows
such as Window 7 and 8.1.  You should use this driver if you only need
support for Windows 10, or you need the Universal driver.  If you require
support on older versions of Windows, you should use the legacy VCP driver
which can be found on the Silicon Labs web site.  The legacy Windows VCP
drivers have version numbers less than 10.0.0.

CONTENTS
--------
The VCP driver package contains the following files and directories:
- silabser.inf -- Driver information file
- SLAB_License_Agreement_VCP_Windows.txt -- Software License
- CP210x_Universal_Windows_Driver_ReleaseNotes.txt -- this file

Additional files needed by installer
- silabser.cat
- x64/silabser.sys
- x86/silabser.sys

INSTALLING
----------
The VCP driver is automatically installed by Windows Update for CP210x with
alternate PID values of 0xEA63, 0xEA7A, and 0xEA7B.  These are not default
values.

Otherwise, unzip the .zip file and you will have a directory containing the
driver installer files.

### Prompted install ###

If Windows prompts you to install a driver for a CP210x device
(for example, if you plug a CP210x into your computer):

1. Use the dialog to browse for the driver location
2. Locate the driver folder (that you previously unzipped)
3. Follow the instructions

### Manual install ###

1. Using Windows File Explorer, locate the driver folder
   (that you previously unzipped)
2. Right click on the silabser.inf file and select Install
3. Follow the instructions

UNINSTALLING
------------
1. The device must be plugged in
2. Run Device Manager
3. Locate the device you want to uninstall
4. Right click on the device and choose "uninstall"
5. Follow the instructions

SUPPORT
-------
For technical support please visit the Silicon Labs support site:

https://www.silabs.com/support

******************************************************************************
    RELEASE NOTES FOR 11.0.0 (2021-11-05)

Changes for VCP Driver
==============================================================================
MCUSW-176    | Add report SERIAL_ERROR_QUEUEOVERRUN when driver-side receive 
             | buffer is overrun
MCUSW-889    | Fixed HLK Test error: Static Tools Logo Test
MCUSW-749    | Fixed issue that RTS is not set to high when Windows goes to 
             | sleep to make sure incoming data to CP210x won't be lost when 
             | Windows is in sleeping state
MCUSW-841    | Removed installer to make a standalone driver package. Users
             | need to use INF file to install the driver instead
MCUSW-906    | Add Microsoft Windows Certified ("WHQL Certified") for Windows 11
             | version 21H2

******************************************************************************
    RELEASE NOTES FOR 10.1.10 (2021-01-13)

Changes for VCP Driver
==============================================================================
MCUSW-651    | Support baud rate up to 2187500 for CP2102, CP2104, CP2109
MCUSW-685    | Fixed the Blue Screen issue when running Windows Hardware Lab   
             | Kit for customized driver                                       
MCUSW-783    | Microsoft Windows Certified (aka "WHQL Certified") for Windows  
             | 10 version 20H2 (2020-10-20)                                    

******************************************************************************
    RELEASE NOTES FOR 10.1.9 (2020-07-30)

Changes for VCP Driver
==============================================================================
MCUSW-566    | Remove sanity/error checking on IOCTL_SERIAL_SET_BAUD_RATE for  
             | CP2103 devices.                                                 
MCUSW-596    | Microsoft Windows Certified (aka "WHQL Certified") for Windows  
             | 10 version 2004 (2020-05-27)                                    
MCUSW-619    | Support for Directed PoFx (DFx - Directed Power Management      
             | Framework).                                                     

******************************************************************************
    RELEASE NOTES FOR 10.1.8 (2019-06-24 (DriverVer = 06/20/2019,10.1.8.2466))

Changes for VCP Driver
==============================================================================
MCUSW-412    | Certified for Windows 10 RS6.                                   
MCUSW-484    | WDFVERIFY() added to the driver. Configurable via Registry.    
MCUSW-493    | Improved the tagging/tracking and parent-hierarchy of framework
             | objects and framework object reference counts. 
MCUSW-495    | Clear RTS on CloseHandle().                                     
MCUSW-508    | IOCTL_SERIAL_GET_COMMSTATUS refactored to reduce USB-bus        
             | bandwidth, while still offering timely reporting.               
MCUSW-518    | WDFVerifier parameter ForceLogsInMiniDump Registry parameter    
             | added for improved supportability.                              
MCUSW-519    | Resolve an SDV-identified issue: do not double-complete a       
             | Request on error paths.                                         
MCUSW-526    | Creates the framework USB device object with client contract    
             | version USBD_CLIENT_CONTRACT_VERSION_602/0x602 (I.e. Register   
             | with "new" (to Windows 8) Windows USB driver stack).            

******************************************************************************
    RELEASE NOTES FOR 10.1.7 (2019-03-26 (DriverVer = 03/26/2019,10.1.7.2399))

Changes for VCP Driver
==============================================================================
MCUSW-473    | Fix length of nul-terminated legacy Dos Name string written to  
             | HARDWARE\DEVICEMAP\SERIALCOMM Registry key.                     
MCUSW-483    | Fixed bug for Max Baud rate for CP2101, CP2104, CP2105 and
             | CP2108 devices.                                                        

******************************************************************************
    RELEASE NOTES FOR 10.1.6 (2019-03-19 (DriverVer = 03/15/2019,10.1.6.2388))

Changes for VCP Driver
==============================================================================
MCUSW-445    | Fix a blue-screen system crash bug with handling of ioctl       
             | IOCTL_SERIAL_WAIT_ON_MASK during power state changes.           

******************************************************************************
    RELEASE NOTES FOR 10.1.5 (2019-02-19 (DriverVer = 02/19/2019,10.1.5.2368))

Changes for VCP Driver
==============================================================================
MCUSW-414    | Implement an undocumented Registry-configured feature to ignore 
             | IOCTL_SERIAL_PURGE.                                             
MCUSW-417    | Read many of the Registry "parameter"-type settings first from  
             | the "parameters key" and then from the "hardware key", with the 
             | "hardware key" taking precedence (allows "driver wide, all      
             | devices" setting, but provides the capability to specify per-   
             | device settings (before we only supported per-device            
             | settings)).                                                     
             |                                                                 
MCUSW-439    | Fixed a bug whereby Close()-Open() on a CP2102N could get USB   
             | data toggle confused (I.e. issue USB CLEAR_FEATURE(HALT) to     
             | bulk endpoints to reset data toggle back to DATA0).             
MCUSW-449    | Fix a Max Baud Rate bug (use device-specific MaxBauds (from the 
             | data-sheets): 3 Mbaud for CP2102N, 1 Mbaud for all other CP210x 
             | devices.).                                                      
MCUSW-450    | Fix Verification BSOD (race condition in the VCP device driver  
             | that can cause double completions): Only call                   
             | DetachForCompletionUNcancelable on success of UNmark as         
             | cancelable in handling of IOCTL_SERIAL_WAIT_ON_MASK-related     
             | requests.                                                       

******************************************************************************
    RELEASE NOTES FOR 10.1.4 (2018-12-07 (DriverVer = 11/26/2018,10.1.4.2290))

Changes for VCP Driver
==============================================================================
MCUSW-134    | Fixed an issue with handling of IOCTL_SERIAL_SET_WAIT_MASK,     
             | IOCTL_SERIAL_WAIT_ON_MASK, with the SERIAL_EV_RXCHAR event and  
             | data arriving from the device into the driver. Previously, an   
             | indication of arriving data was made before making the data     
             | available, causing, in some conditions, subsequent requests for 
             | data after notification of data available to not deliver any    
             | data.                                                           
MCUSW-144    | Onecore-based editions of Windows 10 (I.e. Windows 10 IoT Core) 
             | do not, by design, create PortName entries in the Registry to   
             | specify the device's legacy DOS name (I.e. COM<n).              
             | Consequently, VCP enhanced to not treat this as a failing       
             | condition and to continue without creating legacy COM<n> DOS    
             | devices.                                                        
MCUSW-148    | Rearchitected into two VCP driver packages:                     
             |  1) Windows 7 and later Desktop Editions x86 and x64 driver     
             | package, and                                                    
             |  2) Windows Universal (10 and later; Desktop, tablet, mobile,   
             | embedded) x86, x64, ARM, ARM64 driver package.                  
MCUSW-214    | Windows 10 Universal driver release (I.e. no Windows 7, 8 or    
             | 8.1 support)                                                    
MCUSW-352    | Workaround to issue where close during receipt of serial data   
             | caused CP2102N to hang.                                         
MCUSW-369    | Certified for Windows 10 RS5.                                   
MCUSW-393    | Fix bug due to some BaudRate-related math causing a divide-by-  
             | zero.                                                           
MCUSW-396    | Be defensive against the impossible case of getting a NULL      
             | object in the object completion routine.                        

******************************************************************************
    RELEASE NOTES FOR 10.1.3 (2018-05-29)

Changes for VCP Driver
==============================================================================
MCUSW-326    | Clear DTR on CloseHandle().                                     

******************************************************************************
    RELEASE NOTES FOR 10.1.2 (2018-05-14)

Changes for VCP Driver
==============================================================================
MCUSW-134    | Fixed an issue with handling of IOCTL_SERIAL_SET_WAIT_MASK,     
             | IOCTL_SERIAL_WAIT_ON_MASK, with the SERIAL_EV_RXCHAR event and  
             | data arriving from the device into the driver. Previously, an   
             | indication of arriving data was made before making the data     
             | available, causing, in some conditions, subsequent requests for 
             | data after notification of data available to not deliver any    
             | data.                                                           
MCUSW-211    | Windows 10 Universal driver release (I.e. no Windows 7, 8 or    
             | 8.1 support)                                                    
MCUSW-288    | Fix IOCTL_SERIAL_GET_PROPERTIES.                                
MCUSW-291    | Fix IOCTL_SERIAL_GET_PROPERTIES/SERIAL_COMMPROP for CP210x-like 
             | "Voice MB v2.0" device.                                         
MCUSW-315    | Certified for RS4/1803.                                         

******************************************************************************
    RELEASE NOTES FOR 10.1.1 (DriverVer=11/15/2017,10.1.1.1951)

Changes for VCP Driver
==============================================================================
MCUSW-134    | Fixed an issue with handling of IOCTL_SERIAL_SET_WAIT_MASK,
             | IOCTL_SERIAL_WAIT_ON_MASK, with the SERIAL_EV_RXCHAR event
             | and data arriving from the device into the driver. Previously,
             | an indication of arriving data was made before making the data
             | available, causing, in some conditions, subsequent requests
             | for data after notification of data available to not deliver
             | any data. 

******************************************************************************
LEGACY HISTORY
--------------
Everything below is the shared development history before creation of the
Windows 10 Universal driver.  Everything above is development history of
the Universal driver.

******************************************************************************
    RELEASE NOTES FOR 6.7.5 (2017-10-13)

Changes for VCP Driver
==============================================================================
MCUSW-17     | IOCTL_SERIAL_GET_STATUS TransmittedCount fixed.                 
MCUSW-19     | CP210x_GET_CONFIG_DESCRIPTOR_IOCTL returned byte count fixed.   
MCUSW-21     | Revert IOCTL_SERIAL_GET_COMMSTATUS behaviour to return cached   
             | information (reverse slowdown reported with v6.7.4 in some      
             | applications)                                                   
             |                                                                 
             | Improve windbg logging, w.r.t. doing less when logging is not   
             | enabled (say, Release builds), or when particular subsystem is  
             | not enabled for logging.                                        
             |                                                                 
MCUSW-110    | Windows 10 certified against RS2 (Creators Update).             
MCUSW-207    | In a failed initialization, discard a reference to dynamically  
             | allocated memory once memory has been freed.                    
MCUSW-234    | timestamp SHA2 Signatures with SHA2 timestamps                  

******************************************************************************
    RELEASE NOTES FOR 6.7.4.261 (2017/01/30)

- Device Guard compliant
- CP210XFW-747: Add 3 new parallel PIDs one each for the single-, dual- &
  quad-port CP210x devices (to be distributed via Windows Update)
- CP210XFW-741: Fix driver to use correct interface string index for the
  multi-interface CP210x devices (CP2105 & CP2108). Return iProduct string
  for other CP210x devices.
- CP210XFW-713: Add protection against IRP_MJ_CLOSE coming before
  IRP_MJ_CLEANUP. In such case EvtFileCleanup callback was called with 0
  FileObject, causeing a crash. Serenum is suspected of causing this, even
  though there is no proof except that it's present, was introduced recently
  and this crash was never registered before.
- CP210XFW-691: Fixed race between timer activation and request cancelation
  during processing of read rwquests.
- Changed raw WDF read request timer to our wrapper.
- CP210XFW-693: bugfix: WMI command "wmic path Win32_SerialPort get
  Availability^, DeviceID^, Name" is unable to enumerate the port.
- CP210XFW-686: EvtRequestCancel for wait mask IRP crashed because the
  request was already completed. It didn't serialize well with other places
  that can complete it. It looked like XOff IRP may have the same proble. This
  patch is adding an extra check into *all* other EvtRequestCancel functions
  to make sure this doesn't happen again.
- Changed IOCTLs returning polled-cached MDMSTS to explicitly read the
  status. Use reg value DisableHwAccessInModemStatusIoctls to revert this
  new functionality to old behavior.
- Improved debug prints.
- SerialDbgPrintEx used 1K of stack for the string, reduced to 256.
- Resolved many static Code Analysis warnings
- Added accounting for data in chip's TX queue. Added translation of
  COMM_STATUS::ulErrors into SERIAL_EV_BREAK and SERIAL_EV_ERR.
- CP210XFW-549, CP210XFW-536, CP210XFW-546: Generate events for
  IOCTL_SERIAL_SET_WAIT_MASK from COMM_STATUS::ulErrors. Can be disabled by
  DisableCommStatusPolling reg value.
- Added spinlock around ModemStatus change detection. Refactored modem
  status event signalling to use common function.
- Move passive level functions into the paged section.
- MCUFW-740: Made device close operation wait for chip's Tx queue to empty.
  Added registry settings DisableTxEmptyCheckInClose and
  TxEmptyTimeoutOnCloseInMs.
- Improve control transfer debug prints and clean up code, otherwise no
  functional changes.
- MCUFW-740: Fixed EV_TXEMPTY to account for bytes in chip's Tx queue.
- MCUFW-740: New functions to sync access to comm error storage from
  multiple threads.
- Added DisableTxEmptyCheckInGetCommStatusIoctl reg value.
- Refactor control request I/O. MCUFW-740: Fixed
  IOCTL_SERIAL_GET_COMMSTATUS.
- MCUFW-740: Made device close operation wait for chip's Tx queue to empty.
  Added registry settings DisableTxEmptyCheckInClose and
  TxEmptyTimeoutOnCloseInMs.
- CP210XFW-648: Set a three second timeout on
  WdfUsbTargetDeviceSendControlTransferSynchronously().

******************************************************************************
    RELEASE NOTES FOR 6.7.3 (2016/03/03)

- Down-rev the verison of KMDF the driver uses (CP210XFW-591. Use version of
  KMDF natively included on Windows release)
- Bug fix of blue-screen system crash (CP210XFW-575. driver tries to clear a
  Cancel Routine in a Request that doesn't have it.)

******************************************************************************
    RELEASE NOTES FOR 6.7.2 (2015/11/23)

- Unified Windows 7, 8, 8.1 & 10 support (XP, Vista and Server 2003
  available in version 6.7).
- ARM support added for Windows 10 and Windows 10 IoT Core.
- Silicon Labs-specific Serial Enumeration driver silabenm removed in favor
  of the Windows "in-box" serenm.
- UpperFilter Serial Enumeration driver not enabled by default
- Updated to latest Microsoft build tools
- Resolved /W4 compilation warnings
- Resolved code analysis warnings
- Added a registry value ControlHandShakeForcedSetBits that can force
  certain bits in the ControlHandShake variable to always be set.
- Add SAL-annotations to API header files.
- Bugfix an invalid memory access on device stop.
- Standardize branding Properties resources across all deliverables.
- Digitally sign all signable deliverables.
- Rewrote driver synchronization for data transmission paths.
- Resolve bugs arising from extended stress test.
- Added diagnostic variables to device extension.
- Bugfix a Write IRP stuck forever cauding bugcheck 9f-4 if call to USB
  returns with error.
- Bugfix "packetized write" timeout may fail to act. And improved debug
  prints.
- New reg value DisableS0Idle (default: 0) to replace EnablePowerManagewment
  (default: 0 which actually ment "enable"). Also, DisableS0Idle=1 now
  forces AllowIdleWhileOpen to 0.
- Driver ignores BreakOnEntry, DebugLevel and DebugFlag in registry.
- New CP2108 bug workarounds - GET_LINE_CTL byte swap and tx_empty().
- Fixed crash in read path.
- Simplified, commented and synchronized with NEWSTUFF EvtIoStop and
  EvtIoResume.
- Fixed memory leak on device removal when multiple devices are present.
- Bugfix Read IRP may never complete if other read IRPs are already waiting
  when it arrives.
- Add CP2102N part numbers. Hnadle new part numbers in
  WriteLatch()/ReadLatch().
- Resolve HCK INF warnings that became errors on HLK.
- Bugfix: Potential invalid memory access on device stop.
- Fixed possible memory overrun when writing CP2108 latch.
- Cumulative collection of improvements (due to code analysis, application
  of latest toolset, etc.) and bug fixes.

******************************************************************************
    RELEASE NOTES FOR 6.7.1 (2015/06/29)

- Added certification for Windows 10 Preview (Note: Windows 10 only;
  use v6.7 for Windows prior to Windows 10)

******************************************************************************
    RELEASE NOTES FOR 6.7 (2014/04/11)

- Added vendor-specific commands to the driver that do not affect normal
  operation with standard CP210x devices.
- Modified write behavior to packetize data as a work around for a rare
  USB 2.0 hub behavior seen only in Windows XP (x86).

******************************************************************************
    RELEASE NOTES FOR 6.6.1 (2013/10/24)

- Added certification for Windows 8.1
- Added support for CP2108 devices
- Corrected bug where OS would hang on repetition of many rapid open/closes on
  certain systems.

******************************************************************************
    RELEASE NOTES FOR 6.6

- Moving installer format to DPInst
- Supported under Windows 8
- Corrected bug in total write timeout calculation
- Corrected bug where EV_BREAK event could be misreported based on incoming
  data
- Corrected another BSOD corner case regarding write cancellation

******************************************************************************
    RELEASE NOTES FOR 6.5.3

- Corrected BSOD corner case for a write cancellation
- Corrected memory leak that occurs when a device is plugged/unplugged
  rapidly enough to allow driver startup function to fail

******************************************************************************
    RELEASE NOTES FOR 6.5

- Corrected BSOD corner case issue for handling control requests
- Corrected issue where USB 3.0 hubs would deliver data to the driver out
  of order

******************************************************************************
    RELEASE NOTES FOR 6.4

- Corrected multiple BSOD issues by updating request handling for control
  requests to the USB device, and the write completion method
- Corrected device removal routine to also undo the COM port naming in the
  registry at removal time instead of when the device is closed after the
  removal.

******************************************************************************
    RELEASE NOTES FOR 6.3a

- Updated to 3.2 DriverInstaller to correct a bug seen when updating from an
  old driver installer version	

******************************************************************************
    RELEASE NOTES FOR 6.3

- Corrected a bug introduced in 6.2 which caused BSOD during surprise removal.
- Corrected a bug found in I/O cancellation corner case

******************************************************************************
    RELEASE NOTES FOR 6.2

- Corrected return value for DeviceIoControl() and other COM API functions
  once the device is removed to properly show ERROR_ACCESS_DENIED (0x05)
  instead of ERROR_BAD_COMMAND in GetLastError()
- Corrected bug in DTR/RTS reporting latency seen if you set DTR/RTS and ask
  for it before the device has reported it to the host - now when it is
  written it reads back immediately
- Corrected several USB requests that were improperly defined as device
  requests when they are actually interface requests - this doesn't exhibit
  and bugs in current single interface devices but was changed to be complete
  and correct
- Added support for CP2104 and CP2105 devices	

******************************************************************************
    RELEASE NOTES FOR 6.1

- Corrected a memory leak which could bog the system down after extended use
  of a contiuously opened COM port, and conditionally yield bluescreens on
  certain systems
- Corrected a problem where an IO reqest would sometimes return a busy
  status to user mode, instead the queue is restarted if necessary before
  adding an IO request to the queue
- Corrected a condition which would blue screen on cancelling write request
  that hasn't been fully sent out USB
- Corrected the Capabilites return value, which incorrectly reported that
  timeouts are not supported
- Corrected several Queue size return values, which affected behavior in the
  MSCOMM control
- Corrected DTR/RTS value on device insertion, visible when Serial
  Enumeration is disabled
- Corrected the ability to override Baud Rate and Line Control from the INF
  file

******************************************************************************
    RELEASE NOTES FOR 6.0

- Corrected multiple blue screens and driver hangs related to race
  conditions in the driver
- Corrected problem where driver hangs when 4 or more devices are connected
  to a single transaction translator hub
- Corrected bugs that prohibited serial enumeration
- Corrected problem where IO requests were not completed/cancelled on a
  close
- Corrected problem with dialing out or PPP connections
- Created IO queueing mechanism so that multiple reads, writes, etc. can be
  queued and waited on

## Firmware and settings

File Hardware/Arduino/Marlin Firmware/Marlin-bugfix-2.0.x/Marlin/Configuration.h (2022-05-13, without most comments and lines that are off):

#pragma once
#define CONFIG_EXAMPLES_DIR "Creality/CR-10S/CrealityV1"
#define CONFIGURATION_H_VERSION 02000903
#define STRING_CONFIG_H_AUTHOR "(printedsolid.com, CR-10S)" // Who made the changes.
#define SHOW_BOOTSCREEN
#define SHOW_CUSTOM_BOOTSCREEN
#define CUSTOM_STATUS_SCREEN_IMAGE
#define SERIAL_PORT 0
#define BAUDRATE 115200
  #define MOTHERBOARD BOARD_RAMPS_CREALITY
#define CUSTOM_MACHINE_NAME "CR-10S"
#if LINEAR_AXES >= 4
  #define AXIS4_NAME 'A' // :['A', 'B', 'C', 'U', 'V', 'W']
#endif
#if LINEAR_AXES >= 5
  #define AXIS5_NAME 'B' // :['A', 'B', 'C', 'U', 'V', 'W']
#endif
#if LINEAR_AXES >= 6
  #define AXIS6_NAME 'C' // :['A', 'B', 'C', 'U', 'V', 'W']
#endif
#define EXTRUDERS 1
#define DEFAULT_NOMINAL_FILAMENT_DIA 1.75
#define TEMP_SENSOR_0 1
#define TEMP_SENSOR_1 0
#define TEMP_SENSOR_2 0
#define TEMP_SENSOR_3 0
#define TEMP_SENSOR_4 0
#define TEMP_SENSOR_5 0
#define TEMP_SENSOR_6 0
#define TEMP_SENSOR_7 0
#define TEMP_SENSOR_BED 1
#define TEMP_SENSOR_PROBE 0
#define TEMP_SENSOR_CHAMBER 0
#define TEMP_SENSOR_COOLER 0
#define TEMP_SENSOR_BOARD 0
#define TEMP_SENSOR_REDUNDANT 0
#define DUMMY_THERMISTOR_998_VALUE  25
#define DUMMY_THERMISTOR_999_VALUE 100
#define TEMP_RESIDENCY_TIME         10  // (seconds) Time to wait for hotend to "settle" in M109
#define TEMP_WINDOW                  1  // (°C) Temperature proximity for the "temperature reached" timer
#define TEMP_HYSTERESIS              3  // (°C) Temperature proximity considered "close enough" to the target
#define TEMP_BED_RESIDENCY_TIME     10  // (seconds) Time to wait for bed to "settle" in M190
#define TEMP_BED_WINDOW              1  // (°C) Temperature proximity for the "temperature reached" timer
#define TEMP_BED_HYSTERESIS          3  // (°C) Temperature proximity considered "close enough" to the target
#define TEMP_CHAMBER_RESIDENCY_TIME 10  // (seconds) Time to wait for chamber to "settle" in M191
#define TEMP_CHAMBER_WINDOW          1  // (°C) Temperature proximity for the "temperature reached" timer
#define TEMP_CHAMBER_HYSTERESIS      3  // (°C) Temperature proximity considered "close enough" to the target
#if TEMP_SENSOR_REDUNDANT
  #define TEMP_SENSOR_REDUNDANT_SOURCE    E1  // The sensor that will provide the redundant reading.
  #define TEMP_SENSOR_REDUNDANT_TARGET    E0  // The sensor that we are providing a redundant reading for.
  #define TEMP_SENSOR_REDUNDANT_MAX_DIFF  10  // (°C) Temperature difference that will trigger a print abort.
#endif
#define HEATER_0_MINTEMP   5
#define HEATER_1_MINTEMP   5
#define HEATER_2_MINTEMP   5
#define HEATER_3_MINTEMP   5
#define HEATER_4_MINTEMP   5
#define HEATER_5_MINTEMP   5
#define HEATER_6_MINTEMP   5
#define HEATER_7_MINTEMP   5
#define BED_MINTEMP        5
#define CHAMBER_MINTEMP    5
#define HEATER_0_MAXTEMP 250
#define HEATER_1_MAXTEMP 275
#define HEATER_2_MAXTEMP 275
#define HEATER_3_MAXTEMP 275
#define HEATER_4_MAXTEMP 275
#define HEATER_5_MAXTEMP 275
#define HEATER_6_MAXTEMP 275
#define HEATER_7_MAXTEMP 275
#define BED_MAXTEMP      120
#define CHAMBER_MAXTEMP  60
#define HOTEND_OVERSHOOT 15   // (°C) Forbid temperatures over MAXTEMP - OVERSHOOT
#define BED_OVERSHOOT    10   // (°C) Forbid temperatures over MAXTEMP - OVERSHOOT
#define COOLER_OVERSHOOT  2   // (°C) Forbid temperatures closer than OVERSHOOT
#define PIDTEMP
#define BANG_MAX 255     // Limits current to nozzle while in bang-bang mode; 255=full current
#define PID_MAX BANG_MAX // Limits current to nozzle while PID is active (see PID_FUNCTIONAL_RANGE below); 255=full current
#define PID_K1 0.95      // Smoothing factor within any PID loop
    #define DEFAULT_Kp  22.20
    #define DEFAULT_Ki   1.08
    #define DEFAULT_Kd 114.00
#define MAX_BED_POWER 255 // limits duty cycle to bed; 255=full current
#define MAX_CHAMBER_POWER 255 // limits duty cycle to chamber heater; 255=full current
  #define PID_FUNCTIONAL_RANGE 10 // If the temperature difference between the target temperature and the actual temperature
#define PREVENT_COLD_EXTRUSION
#define EXTRUDE_MINTEMP 170
#define PREVENT_LENGTHY_EXTRUDE
#define EXTRUDE_MAXLENGTH 435
#define THERMAL_PROTECTION_HOTENDS // Enable thermal protection for all extruders
#define THERMAL_PROTECTION_BED     // Enable thermal protection for the heated bed
#define THERMAL_PROTECTION_CHAMBER // Enable thermal protection for the heated chamber
#define THERMAL_PROTECTION_COOLER  // Enable thermal protection for the laser cooling
#define USE_XMIN_PLUG
#define USE_YMIN_PLUG
#define USE_ZMIN_PLUG
#define ENDSTOPPULLUPS
#define X_MIN_ENDSTOP_INVERTING false // Set to true to invert the logic of the endstop.
#define Y_MIN_ENDSTOP_INVERTING false // Set to true to invert the logic of the endstop.
#define Z_MIN_ENDSTOP_INVERTING false // Set to true to invert the logic of the endstop.
#define I_MIN_ENDSTOP_INVERTING false // Set to true to invert the logic of the endstop.
#define J_MIN_ENDSTOP_INVERTING false // Set to true to invert the logic of the endstop.
#define K_MIN_ENDSTOP_INVERTING false // Set to true to invert the logic of the endstop.
#define X_MAX_ENDSTOP_INVERTING false // Set to true to invert the logic of the endstop.
#define Y_MAX_ENDSTOP_INVERTING false // Set to true to invert the logic of the endstop.
#define Z_MAX_ENDSTOP_INVERTING false // Set to true to invert the logic of the endstop.
#define I_MAX_ENDSTOP_INVERTING false // Set to true to invert the logic of the endstop.
#define J_MAX_ENDSTOP_INVERTING false // Set to true to invert the logic of the endstop.
#define K_MAX_ENDSTOP_INVERTING false // Set to true to invert the logic of the endstop.
#define Z_MIN_PROBE_ENDSTOP_INVERTING true  // Set to true to invert the logic of the probe.
#define X_DRIVER_TYPE  A4988
#define Y_DRIVER_TYPE  A4988
#define Z_DRIVER_TYPE  A4988
#define E0_DRIVER_TYPE A4988
#define DEFAULT_AXIS_STEPS_PER_UNIT   { 80, 80, 400, 95 }
#define DEFAULT_MAX_FEEDRATE          { 2500, 2500, 100, 25 }
#define DEFAULT_MAX_ACCELERATION      { 500, 500, 100, 5000 }
#define DEFAULT_ACCELERATION           600    // X, Y, Z and E acceleration for printing moves
#define DEFAULT_RETRACT_ACCELERATION  1000    // E acceleration for retracts
#define DEFAULT_TRAVEL_ACCELERATION    800    // X, Y, Z acceleration for travel (non printing) moves
#define DEFAULT_EJERK    5.0  // May be used by Linear Advance
  #define JUNCTION_DEVIATION_MM 0.067 // (mm) Distance from real junction edge
  #define JD_HANDLE_SMALL_SEGMENTS    // Use curvature estimation instead of just the junction angle
#define S_CURVE_ACCELERATION
#define Z_MIN_PROBE_USES_Z_MIN_ENDSTOP_PIN
#define PROBE_MANUALLY
#define NOZZLE_TO_PROBE_OFFSET { 10, 10, 0 }
#define PROBING_MARGIN 10
#define XY_PROBE_FEEDRATE (133*60)
#define Z_PROBE_FEEDRATE_FAST (8*60)
#define Z_PROBE_FEEDRATE_SLOW (Z_PROBE_FEEDRATE_FAST / 2)
#define Z_CLEARANCE_DEPLOY_PROBE   10 // Z Clearance for Deploy/Stow
#define Z_CLEARANCE_BETWEEN_PROBES  5 // Z Clearance between probe points
#define Z_CLEARANCE_MULTI_PROBE     5 // Z Clearance between multiple probes
#define Z_PROBE_LOW_POINT          -2 // Farthest distance below the trigger-point to go before stopping
#define Z_PROBE_OFFSET_RANGE_MIN -20
#define Z_PROBE_OFFSET_RANGE_MAX 20
#define X_ENABLE_ON 0
#define Y_ENABLE_ON 0
#define Z_ENABLE_ON 0
#define E_ENABLE_ON 0 // For all extruders
#define DISABLE_X false
#define DISABLE_Y false
#define DISABLE_Z false
#define DISABLE_E false             // Disable the extruder when not stepping
#define DISABLE_INACTIVE_EXTRUDER   // Keep only the active extruder enabled
#define INVERT_X_DIR false
#define INVERT_Y_DIR false
#define INVERT_Z_DIR true
#define INVERT_E0_DIR false
#define INVERT_E1_DIR false
#define INVERT_E2_DIR false
#define INVERT_E3_DIR false
#define INVERT_E4_DIR false
#define INVERT_E5_DIR false
#define INVERT_E6_DIR false
#define INVERT_E7_DIR false
#define X_HOME_DIR -1
#define Y_HOME_DIR -1
#define Z_HOME_DIR -1
#define X_BED_SIZE 296 // Nozzle is at X4 when homed
#define Y_BED_SIZE 298 // Nozzle is at Y2 when homed
#define X_MIN_POS 4
#define Y_MIN_POS 2
#define Z_MIN_POS 0
#define X_MAX_POS 319 // 15mm Extra space on the right end
#define Y_MAX_POS 306 // 4mm Extra space behind the bed
#define Z_MAX_POS 400
#define MIN_SOFTWARE_ENDSTOPS
  #define MIN_SOFTWARE_ENDSTOP_X
  #define MIN_SOFTWARE_ENDSTOP_Y
  #define MIN_SOFTWARE_ENDSTOP_Z
  #define MIN_SOFTWARE_ENDSTOP_I
  #define MIN_SOFTWARE_ENDSTOP_J
  #define MIN_SOFTWARE_ENDSTOP_K
#define MAX_SOFTWARE_ENDSTOPS
  #define MAX_SOFTWARE_ENDSTOP_X
  #define MAX_SOFTWARE_ENDSTOP_Y
  #define MAX_SOFTWARE_ENDSTOP_Z
  #define MAX_SOFTWARE_ENDSTOP_I
  #define MAX_SOFTWARE_ENDSTOP_J
  #define MAX_SOFTWARE_ENDSTOP_K
#define FILAMENT_RUNOUT_SENSOR
  #define FIL_RUNOUT_ENABLED_DEFAULT true // Enable the sensor on startup. Override with M412 followed by M500.
  #define NUM_RUNOUT_SENSORS   1          // Number of sensors, up to one per extruder. Define a FIL_RUNOUT#_PIN for each.
  #define FIL_RUNOUT_PIN 2 // Creality CR-10S stock sensor
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

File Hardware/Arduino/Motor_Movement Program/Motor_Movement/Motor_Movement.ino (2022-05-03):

#include <SpeedyStepper.h>

//X Stepper
const int STEP_PIN_X = 54; 
const int DIR_PIN_X = 55;
const int ENABLE_PIN_X = 38; 
const int MIN_PIN_X = 3;
const int MAX_PIN_X = 2;
SpeedyStepper x_stepper;

//Y Stepper  
const int STEP_PIN_Y = 60;
const int DIR_PIN_Y = 61; 
const int ENABLE_PIN_Y = 56; 
const int MIN_PIN_Y = 14;
const int MAX_PIN_Y = 15;
SpeedyStepper y_stepper;

//Z Stepper 
const int STEP_PIN_Z = 46;
const int DIR_PIN_Z = 48;
const int ENABLE_PIN_Z = 62; 
const int MIN_PIN_Z = 18;
const int MAX_PIN_Z = 19;
SpeedyStepper z_stepper;


//Max Millimeter(mm) values that can be applied (300,280,245)
const int MAX_X_VALUE = 280; 
const int MAX_Y_VALUE = 280; 
const int MAX_Z_VALUE = 340; 

//MIDDLE FOR SENSOR: 150,140,245 


//void move_stepper(int x,int y, int z){ 
//    x_stepper.moveToPositionInSteps(-x);
//    y_stepper.moveToPositionInSteps(-y);
//    z_stepper.moveToPositionInSteps(-z);
//}
//
//void move_home(){ 
//  x_stepper.moveToHomeInSteps(-1,600,100000,MIN_PIN_X);
//  y_stepper.moveToHomeInSteps(-1,600,100000,MIN_PIN_Y);
//  z_stepper.moveToHomeInSteps(1,600,100000,MIN_PIN_Z);
//}


void mm_move_stepper(int x,int y, int z){ 
  if(x>MAX_X_VALUE){
   x = MAX_X_VALUE;
  }
  if(y>MAX_Y_VALUE){ 
    y = MAX_Y_VALUE;
  }
  if(z>MAX_Z_VALUE){ 
    z = MAX_Z_VALUE;
  }
  z_stepper.moveToPositionInMillimeters(z);
  x_stepper.moveToPositionInMillimeters(-x);
  y_stepper.moveToPositionInMillimeters(-y);
  

}

void mm_move_home(){
  x_stepper.moveToHomeInMillimeters(-1,5,100000,MIN_PIN_X);
  y_stepper.moveToHomeInMillimeters(-1,5,100000,MIN_PIN_Y);
  z_stepper.moveToHomeInMillimeters(1,5,100000,MIN_PIN_Z);
  
}

int x1; 
int y1; 
int z1; 

int Position[3];
void setup() {
  Serial.begin(115200); //communication
  Serial.setTimeout(1); 



  //Sets Enable pins to Low 
  pinMode(ENABLE_PIN_X,OUTPUT); 
  digitalWrite(ENABLE_PIN_X,LOW);
  x_stepper.connectToPins(STEP_PIN_X, DIR_PIN_X);  //connects step and direction pins X

  pinMode(ENABLE_PIN_Y,OUTPUT); 
  digitalWrite(ENABLE_PIN_Y,LOW);
  y_stepper.connectToPins(STEP_PIN_Y, DIR_PIN_Y);  //connects step and direction pins Y

  
  pinMode(ENABLE_PIN_Z,OUTPUT); 
  digitalWrite(ENABLE_PIN_Z,LOW);
  z_stepper.connectToPins(STEP_PIN_Z, DIR_PIN_Z);  //connects step and direction pins Z

  x_stepper.setStepsPerMillimeter(85);
  x_stepper.setSpeedInMillimetersPerSecond(30);
  x_stepper.setAccelerationInMillimetersPerSecondPerSecond(30); 
  
  y_stepper.setStepsPerMillimeter(85);
  y_stepper.setSpeedInMillimetersPerSecond(30);
  y_stepper.setAccelerationInMillimetersPerSecondPerSecond(30); 

  z_stepper.setStepsPerMillimeter(400);
  z_stepper.setSpeedInMillimetersPerSecond(30);
  z_stepper.setAccelerationInMillimetersPerSecondPerSecond(30); 
  
//  x_stepper.setSpeedInStepsPerSecond(5000); 
//  x_stepper.setAccelerationInStepsPerSecondPerSecond(5000);
//  y_stepper.setSpeedInStepsPerSecond(5000); 
//  y_stepper.setAccelerationInStepsPerSecondPerSecond(5000);
//  z_stepper.setSpeedInStepsPerSecond(5000); 
//  z_stepper.setAccelerationInStepsPerSecondPerSecond(5000);

//  mm_move_home();
//  //mm_move_stepper(300,280,345); //MAX S
//  mm_move_stepper(150,140,172); //HALF 
//  mm_move_home(); 

mm_move_home();
mm_move_stepper(135,100,280);

}

bool newData = false;
char t[15]={'\0'};
int c = 0;


void recieve(){ 
  char endMarker =')';
  char begMarker='(';
  char rc; 
  while(Serial.available() > 0 && newData == false){ 
    rc = Serial.read(); 

    if(rc!= endMarker){
      if(rc!=begMarker){
        t[c] = rc; 
        c++; 
      }
    }
    else{ 
      t[c] = '\0';
      c = 0; 
      newData = true;

      //splits string when it recieves full string 
      int c = 0; 
      int Posi = 0;
      int i = 0;
      while(c!=3){ 
        String temp =""; 
        while(t[i]!=','){
          temp+=t[i];
          i++; 
         }
         i++;
         Position[Posi] = temp.toInt();
         Posi++;
         c++;
      }
      
      mm_move_stepper(Position[0],Position[1],Position[2]); 
      newData = false;
        
    }
  }
}


void loop() {
  
 recieve(); 

  
}

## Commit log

2022-03-06 Motor Movement and Design Addition
    [Sensor_Camera_v2 .stl]
2022-03-08 Added Movement Buttons for Motors
2022-03-08 Arduino&Buttons Implement
2022-03-09 addition of threads
2022-03-09 Thread Test 2
2022-03-10 Thread Arduino works
2022-03-18 Reading the Sensor data with driver info
2022-03-18 Fixed Motor Movement
2022-03-21 Added Start and Stop Scan Button
2022-03-21 Semi-working motors- editted serial data
2022-03-22 Final Fix Motor Movement and Read Serial
    [APST_GUI.py, Motor_Movement.ino]
2022-03-25 Plotting Data - stop button not working
    [SensorData.csv]
2022-03-28 Changed Pressure
2022-04-28 Working motors with GUI
2022-04-28 Cleaning and switching to main APST file
    [SensorData.csv]
2022-05-02 Changed the Camera button
2022-05-02 Added camera on/off
2022-05-05 Added sensor track
2022-05-06 fixed sensor
    [Pulse Hold Piece v1.f3d, Pulse Hold Piece v1.obj, Pulse Hold Piece v2.obj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]
2022-05-09 Moved motors automatically
2022-05-10 Fixed Instructions: Automatic working
    [APST_GUI.py]
2022-05-10 Fixed Detect/Stop Frame
2022-05-13 Organize pt3 - Code
    [Configuration.h, Configuration_adv.h, Pulse Hold Piece v1.f3d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]

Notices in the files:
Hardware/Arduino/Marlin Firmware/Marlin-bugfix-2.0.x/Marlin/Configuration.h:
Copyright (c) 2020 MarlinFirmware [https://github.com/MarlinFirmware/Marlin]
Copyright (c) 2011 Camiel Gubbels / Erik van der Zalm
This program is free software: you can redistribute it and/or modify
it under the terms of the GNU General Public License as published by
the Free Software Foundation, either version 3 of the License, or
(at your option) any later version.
